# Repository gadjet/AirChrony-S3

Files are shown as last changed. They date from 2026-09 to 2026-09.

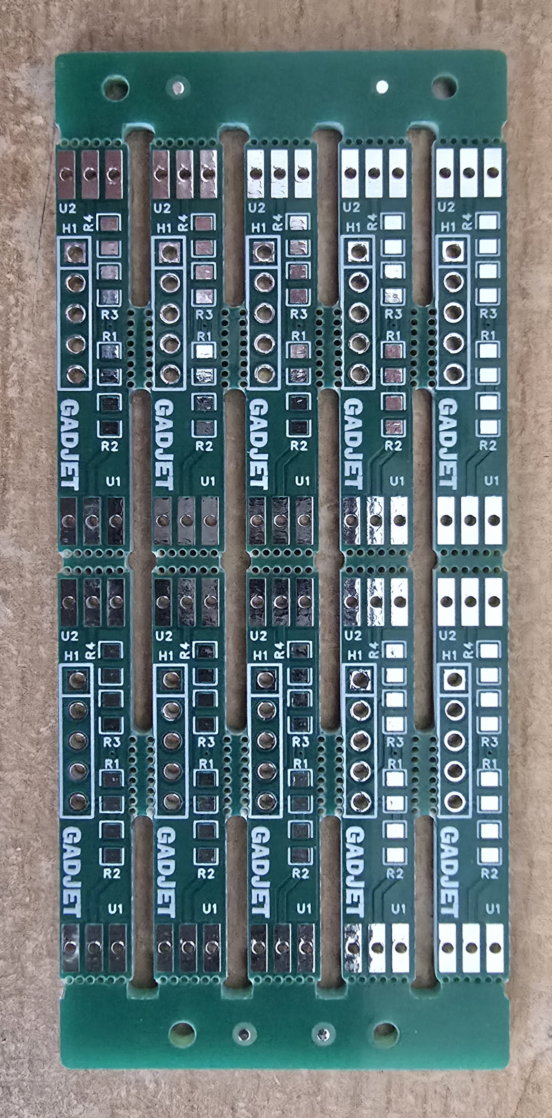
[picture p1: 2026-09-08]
PCB Files/Detector PCB/20260908_100754.jpg

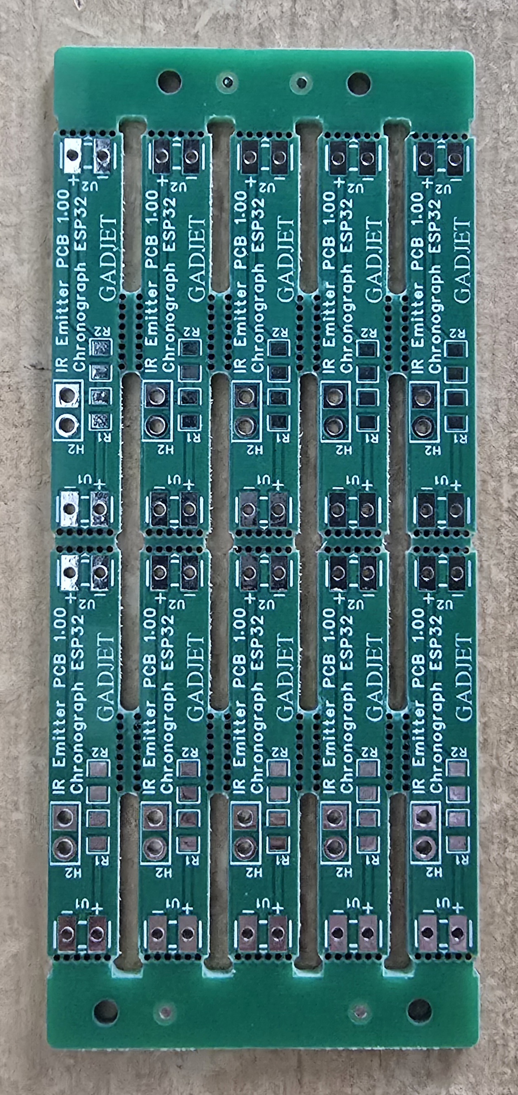
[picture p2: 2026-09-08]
PCB Files/Emitter PCB/20260908_100842.jpg

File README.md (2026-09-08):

# AirChrony-S3
DIY Chronograph revisited

This project is still a work in progress.
It's been about 10 years since my first blog entry on my DIY chronograph using an Ardunino Nano and a Bluetooth transmitter.  This connected to an app on my phone and transmitted the time between trigger 1 and 2, which the app then used, along with the pellet weight, to calculate the speed and power of the rifle/pistol.

I have a few projects under my belt since then and although I enjoy designing the hardware I'm not so good at writing the software needed to operate it.

As many others have done I've started using AI, specifically Google Gemini, to help writing code for, not just the hardware, but also the user interface on the phone/PC.

I realised that I could revisit the DIY Chronograph using an EPS32, my favorite being the Xiao ESP32 - S3 from Seeedstudio.  This runs at 240MHz which is a little faster than the older Arduino Nano and with it also having it's own webserver capability I could include the user interface on the Chronograph itself and just visit the webpage to interact with the device (this can be done on your phone, tablet or laptop).

Hardware
The basics are much the same as the original design with a couple of IR emitters and detectors spaced 50mm apart creating two beams that when broken start and end a timer that measures how long it takes for the pellet to travel 50mm and from that the speed of the pellet can be determined.

Chronograph - Top Down Section View
**General layout
**
Chronograph - Side Section View
General layout Side Sectionpng
 
Chronograph - X-RAY View
X-Ray View

The outer casing is made in two parts that slide over the electronics and tube, they interface using two 2mm dowels and an M3 screw to lock them together.


Currently power is supplied using a USB C lead from a 5V power source but I may add an internal battery later.  Please note: the USB power lead head will need to be narrow enough to fit in the recess which is 11.5mm x 6.5mm.

With the original design this "time" value was transmitted to the phone where the app would calculate the speed/power etc. with the ESP32 solution all the calculations are done on the device and placed on the webpage on the ESP32 server.  To view the User Interface you just connect you device to the WiFi "AirChrony3" then visit "192.168.4.1" with your browser.
User interface
The user interface opens to show the current shot data on the "Live Chrono" tab, there are other tabs including "Pellet profiles" here you can add details of your pellets like brand and size and weight, you can pick from these profiles to calculate the power of the airgun.  There is also a "settings" tab where you can change things like voice announcements, distance between the sensors and other things.

This interface is constantly under revision as I think of new things and you are welcome to use AI to create your own specific user interface.

## Assembled parts






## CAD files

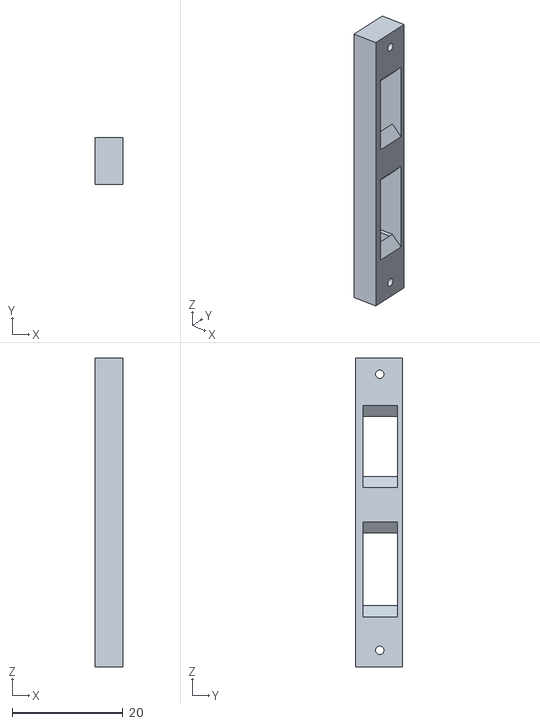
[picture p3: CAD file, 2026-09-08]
3D STL files/Emitter_Detector assembley jig.stl
5.08 x 8.44 x 55.9

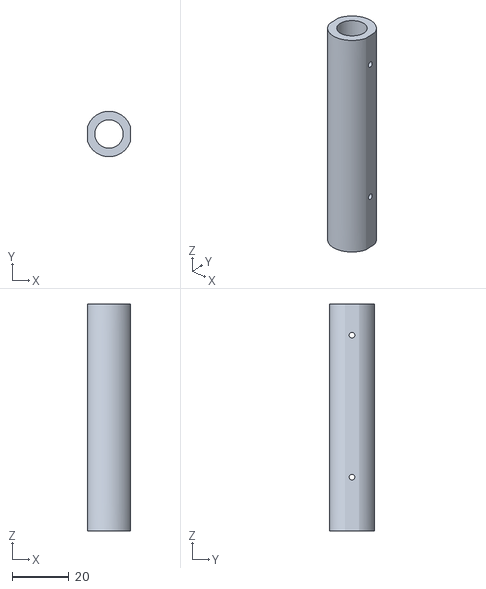
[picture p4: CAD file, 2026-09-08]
3D STL files/Tube.stl
15.3 x 16.0 x 80.0

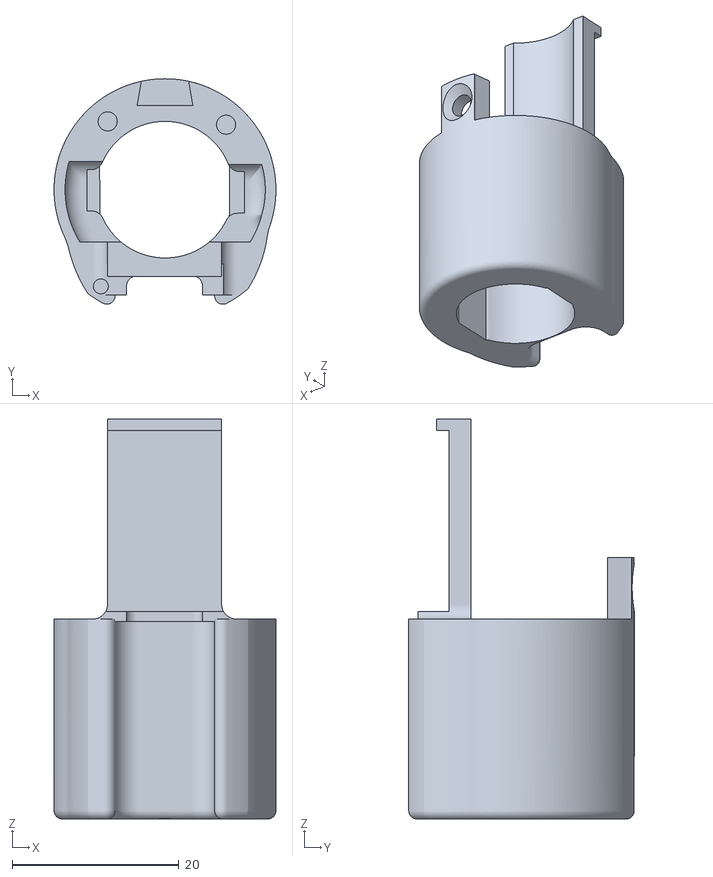
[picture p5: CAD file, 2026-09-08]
3D STL files/Front.stl
26.6 x 27.1 x 48.0

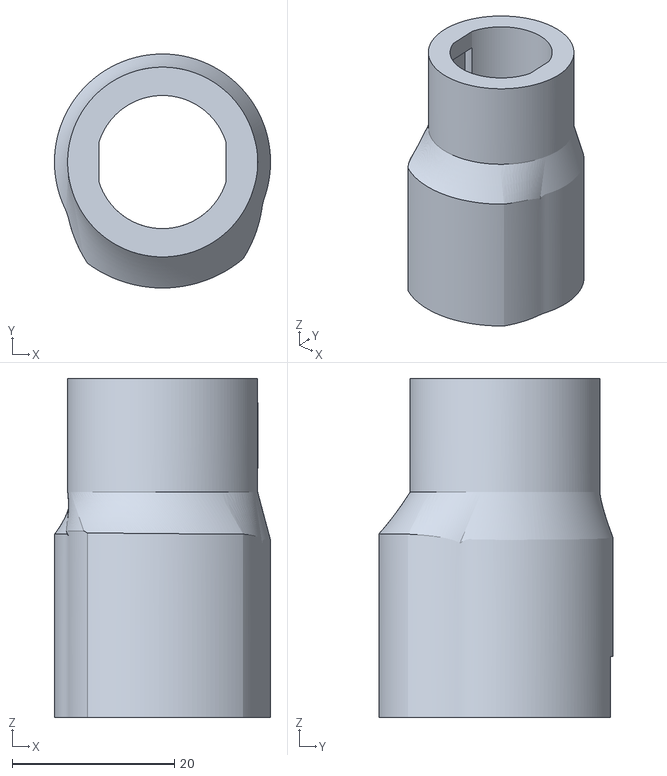
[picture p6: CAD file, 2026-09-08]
3D STL files/Rear.stl
26.6 x 28.8 x 41.8

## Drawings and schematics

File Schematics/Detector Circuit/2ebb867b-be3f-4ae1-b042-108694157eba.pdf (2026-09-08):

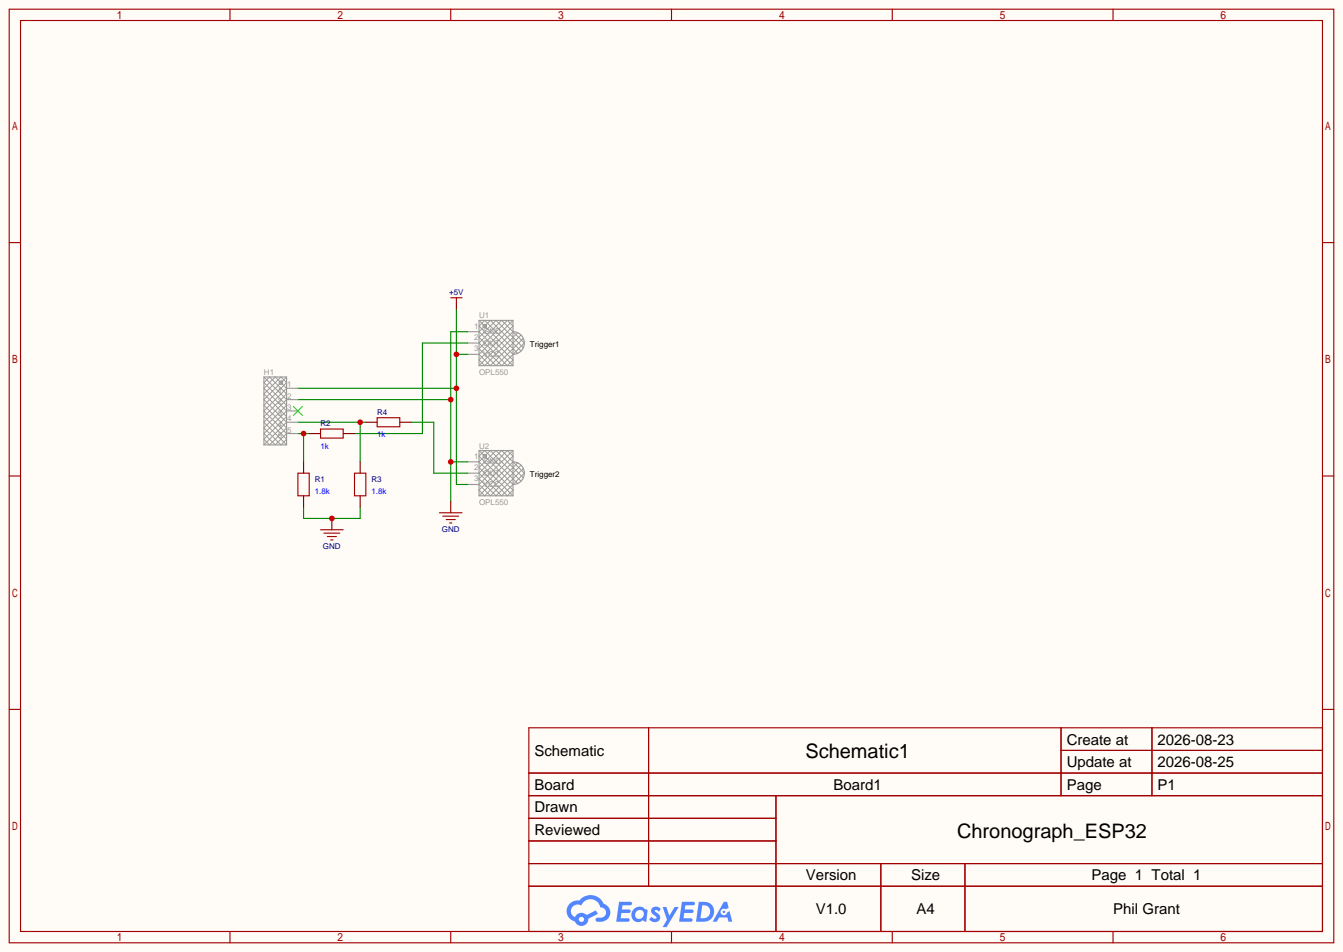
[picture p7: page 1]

Schematic | Schematic1 | Create at | 2026-08-23

Update at | 2026-08-25

Board | Board1 | Page | P1
Drawn | | Chronograph_ESP32
Reviewed

Version | Size | Page 1 Total 1
V1.0 | A4 | Phil Grant

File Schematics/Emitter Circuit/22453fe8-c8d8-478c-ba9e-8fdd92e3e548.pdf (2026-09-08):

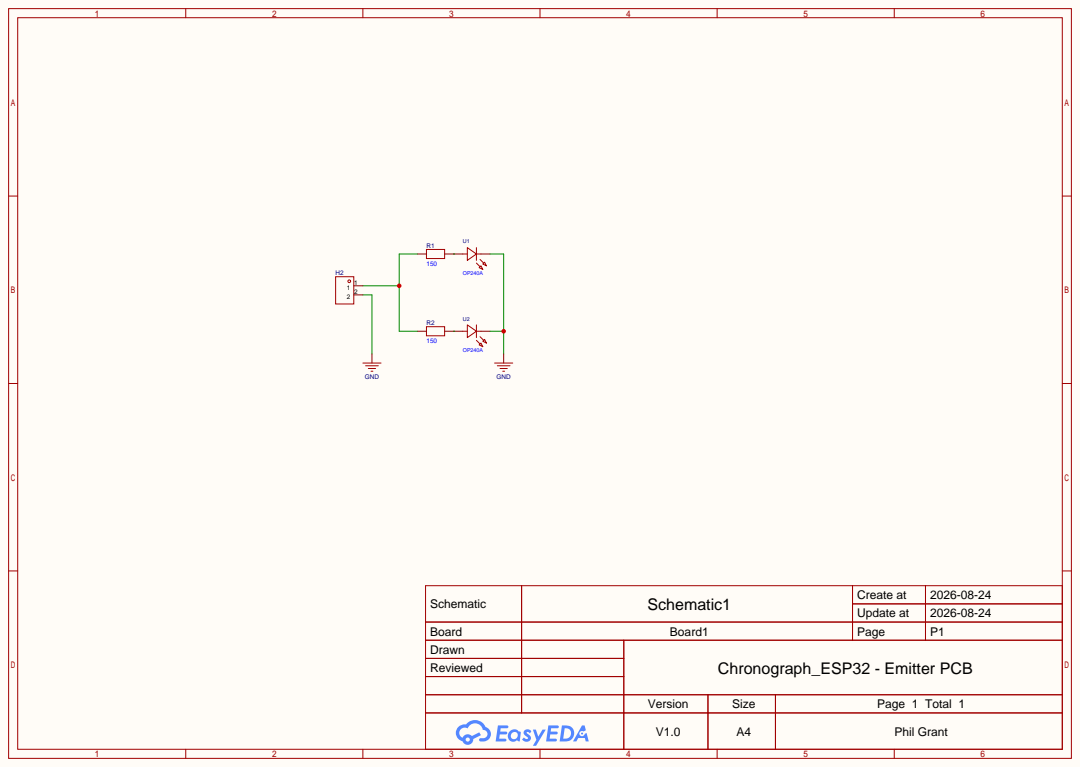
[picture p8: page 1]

Schematic | Schematic1 | Create at | 2026-08-24

Update at | 2026-08-24

Board | Board1 | Page | P1
Drawn | | Chronograph_ESP32 - Emitter PCB
Reviewed

Version | Size | Page 1 Total 1
V1.0 | A4 | Phil Grant

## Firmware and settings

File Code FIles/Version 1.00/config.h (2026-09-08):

#ifndef CONFIG_H
#define CONFIG_H

#include <Arduino.h>

// ==============================================================================
// HARDWARE PIN DEFINITIONS FOR SEED STUDIO XIAO ESP32-S3
// ==============================================================================
// Seeed Studio XIAO ESP32-S3 Pin Mapping:
// D0 -> GPIO 1  (Assigned to: IR Emitters Ground Sink - LOW)
// D1 -> GPIO 2  (Assigned to: IR Emitters Power Control via 2x 150Ω resistors - HIGH)
// D2 -> GPIO 3
// D3 -> GPIO 4
// D4 -> GPIO 5
// D5 -> GPIO 6
// D6 -> GPIO 43 (TX)
// D7 -> GPIO 44 (RX)
// D8 -> GPIO 7  (SCL)
// D9 -> GPIO 8  (Assigned to: Gate 2 Stop Sensor DOUT)
// D10-> GPIO 9  (Assigned to: Gate 1 Start Sensor DOUT)
// Built-in User LED: GPIO 21 (Active LOW on XIAO ESP32-S3)
// ==============================================================================

#if defined(CONFIG_IDF_TARGET_ESP32C3)
  #define PIN_GATE_1          10  // D10 on XIAO C3 (GPIO 10) - First optical IR sensor (Start)
  #define PIN_GATE_2          9   // D9  on XIAO C3 (GPIO 9)  - Second optical IR sensor (Stop)
  #define PIN_IR_EMITTER      3   // D1  on XIAO C3 (GPIO 3)  - Power feed (HIGH) to 2x IR emitter LEDs
  #define PIN_IR_EMITTER_GND  2   // D0  on XIAO C3 (GPIO 2)  - Ground sink (LOW) for 2x IR emitter LEDs
  #define PIN_STATUS_LED      10  // Built-in LED on XIAO C3
#else
  #define PIN_GATE_1          9   // D10 on XIAO S3 (GPIO 9)  - First optical IR sensor (Start)
  #define PIN_GATE_2          8   // D9  on XIAO S3 (GPIO 8)  - Second optical IR sensor (Stop)
  #define PIN_IR_EMITTER      2   // D1  on XIAO S3 (GPIO 2)  - Power feed (HIGH) to 2x IR emitter LEDs via 150Ω
  #define PIN_IR_EMITTER_GND  1   // D0  on XIAO S3 (GPIO 1)  - Ground sink (LOW) for 2x IR emitter LEDs
  #define PIN_STATUS_LED      21  // On-board LED for visual shot / AP indication (Active LOW on XIAO S3)
#endif

// Default trigger interrupt mode:
// Most digital IR receiver boards (phototransistor + LM393 comparator) output LOW
// when the IR beam is interrupted (falling edge) or HIGH (rising edge).
#define DEFAULT_TRIGGER_MODE FALLING 

// ==============================================================================
// DEFAULT MEASUREMENT & POWER SAVING PARAMETERS
// ==============================================================================
#define DEFAULT_GATE_DISTANCE_MM    50.0f    // Distance between Gate 1 and Gate 2 in millimeters
#define MIN_GATE_DISTANCE_MM        10.0f
#define MAX_GATE_DISTANCE_MM        300.0f

#define SHOT_TIMEOUT_MICROS         500000UL // 500ms timeout (allows slow gravity drop testing and low velocity projectiles)
#define MIN_SHOT_INTERVAL_MICROS    50000UL  // 50ms dead-time after a shot before arming next

#define DEFAULT_EMITTER_TIMEOUT_MIN 10       // Emitter power-saving sleep timeout in minutes (0 = always on)

// ==============================================================================
// DEFAULT PELLET SETTINGS
// ==============================================================================
#define DEFAULT_PELLET_BRAND        "JSB"
#define DEFAULT_PELLET_MODEL        "Exact Diabolo"
#define DEFAULT_PELLET_GRAINS       8.44f
#define DEFAULT_CALIBER             ".177 (4.5mm)"
#define DEFAULT_AVG_WINDOW          10       // Default rolling average shot window

// Unit Conversion Constants
#define GRAINS_TO_GRAMS             0.06479891f
#define GRAMS_TO_GRAINS             15.4323584f
#define MPS_TO_FPS                  3.280839895f
#define FPS_TO_MPS                  0.3048f
#define JOULES_TO_FTLBS             0.737562149f
#define FTLBS_TO_JOULES             1.355817948f

// ==============================================================================
// WIFI & ACCESS POINT CONFIGURATION
// ==============================================================================
#define AP_SSID                     "AirChrony-S3"
#define AP_PASSWORD                 ""          // Open network by default for convenience
#define AP_CHANNEL                  1
#define AP_MAX_CONN                 4

#define MDNS_HOSTNAME               "chronograph" // Accessible at http://chronograph.local

#define MAX_SHOTS_PER_STRING        250         // Memory safety buffer for single string
#define MAX_SAVED_STRINGS           50          // Max string files stored in LittleFS

#endif // CONFIG_H

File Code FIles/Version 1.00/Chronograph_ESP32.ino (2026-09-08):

#include <Arduino.h>
#include <WiFi.h>
#include <WebServer.h>
#include <DNSServer.h>
#include <ESPmDNS.h>
#include "config.h"
#include "ChronoEngine.h"
#include "StorageManager.h"
#include "WebPages.h"

// Core Engines
ChronoEngine engine;
StorageManager storage;

// Networking
WebServer server(80);
DNSServer dnsServer;
const byte DNS_PORT = 53;

// Helper to extract JSON parameter from body
String getJsonField(const String& body, const String& field) {
    int idx = body.indexOf("\"" + field + "\"");
    if (idx == -1) return "";
    int colon = body.indexOf(':', idx);
    if (colon == -1) return "";
    int start = colon + 1;
    while (start < (int)body.length() && (body[start] == ' ' || body[start] == '\t' || body[start] == '\n' || body[start] == '\r')) start++;
    if (start >= (int)body.length()) return "";

    if (body[start] == '\"') {
        int end = body.indexOf('\"', start + 1);
        if (end == -1) return "";
        return body.substring(start + 1, end);
    } else {
        int end = start;
        while (end < (int)body.length() && body[end] != ',' && body[end] != '}' && body[end] != ' ' && body[end] != '\n' && body[end] != '\r') end++;
        return body.substring(start, end);
    }
}

// HTTP Route Handlers
void handleRoot() {
    engine.refreshActivity();
    server.send_P(200, "text/html", PAGE_INDEX);
}

void handleGetState() {
    String json = storage.stringToJson(engine);
    server.send(200, "application/json", json);
}

void handleGetLive() {
    String json = "{";
    json += "\"totalShots\":" + String(engine.shots.size()) + ",";
    json += "\"state\":" + String((int)engine.getState()) + ",";
    json += "\"emittersPowered\":" + String(engine.emittersPowered ? "true" : "false");
    json += "}";
    server.send(200, "application/json", json);
}

void handlePostPellet() {
    engine.refreshActivity();
    if (server.hasArg("plain")) {
        String body = server.arg("plain");
        
        String brand = getJsonField(body, "brand");
        if (brand.length() > 0) engine.pellet.brand = brand;

        String model = getJsonField(body, "model");
        if (model.length() > 0) engine.pellet.model = model;

        String cal = getJsonField(body, "caliber");
        if (cal.length() > 0) engine.pellet.caliber = cal;

        String gr = getJsonField(body, "weightGrains");
        if (gr.length() > 0) engine.pellet.setWeightGrains(gr.toFloat());

        String win = getJsonField(body, "avgWindowSize");
        if (win.length() > 0) engine.avgWindowSize = win.toInt();

        engine.recalculateStatistics();
        storage.saveSettings(engine);

        server.send(200, "application/json", "{\"status\":\"ok\"}");
        return;
    }
    server.send(400, "application/json", "{\"error\":\"Missing body\"}");
}

void handlePostHardware() {
    engine.refreshActivity();
    if (server.hasArg("plain")) {
        String body = server.arg("plain");
        
        String dist = getJsonField(body, "gateDistanceMm");
        if (dist.length() > 0) engine.gateDistanceMm = dist.toFloat();

        String trig = getJsonField(body, "triggerMode");
        if (trig.length() > 0) {
            engine.triggerMode = trig.toInt();
            engine.attachGateInterrupts();
        }

        String emitTimeout = getJsonField(body, "emitterTimeoutMin");
        if (emitTimeout.length() > 0) {
            engine.emitterTimeoutMin = emitTimeout.toInt();
        }

        storage.saveSettings(engine);
        server.send(200, "application/json", "{\"status\":\"ok\"}");
        return;
    }
    server.send(400, "application/json", "{\"error\":\"Missing body\"}");
}

void handlePostEmitters() {
    engine.refreshActivity();
    if (server.hasArg("plain")) {
        String body = server.arg("plain");
        String en = getJsonField(body, "enabled");
        if (en == "true") {
            engine.setEmitters(true);
        } else if (en == "false") {
            engine.setEmitters(false);
        } else {
            // Toggle
            engine.setEmitters(!engine.emittersPowered);
        }
    } else {
        engine.setEmitters(!engine.emittersPowered);
    }
    String json = "{\"status\":\"ok\",\"emittersPowered\":" + String(engine.emittersPowered ? "true" : "false") + "}";
    server.send(200, "application/json", json);
}

void handleGetSensors() {
    engine.refreshActivity();
    // Read direct digital pin states for sensor alignment test
    bool g1 = (digitalRead(PIN_GATE_1) == (engine.triggerMode == FALLING ? LOW : HIGH));
    bool g2 = (digitalRead(PIN_GATE_2) == (engine.triggerMode == FALLING ? LOW : HIGH));

    String json = "{";
    json += "\"gate1\":" + String(g1 ? "true" : "false") + ",";
    json += "\"gate2\":" + String(g2 ? "true" : "false") + ",";
    json += "\"emittersPowered\":" + String(engine.emittersPowered ? "true" : "false");
    json += "}";
    server.send(200, "application/json", json);
}

void handleSimulateShot() {
    engine.simulateShot(785.0f, 6.0f);
    server.send(200, "application/json", "{\"status\":\"simulated\"}");
}

void handleDeleteShot() {
    engine.refreshActivity();
    if (server.hasArg("index")) {
        int idx = server.arg("index").toInt();
        engine.deleteShot(idx);
        server.send(200, "application/json", "{\"status\":\"deleted\"}");
        return;
    }
    server.send(400, "application/json", "{\"error\":\"Missing index\"}");
}

void handleResetSession() {
    engine.resetSession();
    server.send(200, "application/json", "{\"status\":\"reset\"}");
}

void handleSaveString() {
    engine.refreshActivity();
    String name = "";
    if (server.hasArg("plain")) {
        name = getJsonField(server.arg("plain"), "name");
    }
    String id = storage.saveShotString(engine, name);
    if (id.length() > 0) {
        server.send(200, "application/json", "{\"status\":\"saved\",\"id\":\"" + id + "\"}");
    } else {
        server.send(500, "application/json", "{\"error\":\"Save failed\"}");
    }
}

void handleListStrings() {
    engine.refreshActivity();
    String listJson = storage.listSavedStrings();
    server.send(200, "application/json", listJson);
}

void handleLoadString() {
    engine.refreshActivity();
    if (server.hasArg("id")) {
        String id = server.arg("id");
        String json = storage.getShotStringJson(id);
        if (json.length() > 2) {
            server.send(200, "application/json", json);
            return;
        }
    }
    server.send(404, "application/json", "{\"error\":\"Not found\"}");
}

void handleDeleteSavedString() {
    engine.refreshActivity();
    if (server.hasArg("id")) {
        String id = server.arg("id");
        storage.deleteShotString(id);
        server.send(200, "application/json", "{\"status\":\"deleted\"}");
        return;
    }
    server.send(400, "application/json", "{\"error\":\"Missing id\"}");
}

void handleExportActiveCSV() {
    engine.refreshActivity();
    String csv = storage.generateCSV(engine);
    server.sendHeader("Content-Disposition", "attachment; filename=\"active_shot_string.csv\"");
    server.send(200, "text/csv", csv);
}

void handleExportSavedCSV() {
    engine.refreshActivity();
    if (server.hasArg("id")) {
        String id = server.arg("id");
        String json = storage.getShotStringJson(id);
        server.sendHeader("Content-Disposition", "attachment; filename=\"string_" + id + ".json\"");
        server.send(200, "application/json", json);
        return;
    }
    server.send(400, "text/plain", "Missing string id");
}

void handleNotFound() {
    String host = server.hostHeader();
    if (host != "192.168.4.1" && host != "chronograph.local") {
        server.sendHeader("Location", "http://192.168.4.1/", true);
        server.send(302, "text/plain", "");
        return;
    }
    server.send(404, "text/plain", "Not Found");
}

void setup() {
    Serial.begin(115200);
    delay(500);
    Serial.println();
    Serial.println(F("========================================"));
    Serial.println(F("  AirChrony S3 Precision Chronograph    "));
    Serial.println(F("  Gate 1: D10 (GPIO9) | Gate 2: D9 (GPIO8) "));
    Serial.println(F("  IR Emitters: D1 (GPIO2) via 2x 150R   "));
    Serial.println(F("========================================"));

    // Initialize Storage
    storage.begin();

    // Initialize Chronograph Engine & Sensors
    engine.begin();
    storage.loadSettings(engine);

    // Initialize WiFi in Access Point mode
    WiFi.mode(WIFI_AP);
    IPAddress local_ip(192, 168, 4, 1);
    IPAddress gateway(192, 168, 4, 1);
    IPAddress subnet(255, 255, 255, 0);
    WiFi.softAPConfig(local_ip, gateway, subnet);
    WiFi.softAP(AP_SSID, AP_PASSWORD, AP_CHANNEL, 0, AP_MAX_CONN);

    Serial.print(F("[WiFi] Access Point Created: "));
    Serial.println(AP_SSID);
    Serial.print(F("[WiFi] Connect to: http://"));
    Serial.println(WiFi.softAPIP());

    // Start DNS Captive Portal
    dnsServer.setErrorReplyCode(DNSReplyCode::NoError);
    dnsServer.start(DNS_PORT, "*", local_ip);

    // Start mDNS Responder
    if (MDNS.begin(MDNS_HOSTNAME)) {
        Serial.println(F("[mDNS] Responding at http://chronograph.local"));
        MDNS.addService("http", "tcp", 80);
    }

    // Configure WebServer Routes
    server.on("/", HTTP_GET, handleRoot);
    server.on("/api/state", HTTP_GET, handleGetState);
    server.on("/api/live", HTTP_GET, handleGetLive);
    server.on("/api/pellet", HTTP_POST, handlePostPellet);
    server.on("/api/hardware", HTTP_POST, handlePostHardware);
    server.on("/api/emitters", HTTP_POST, handlePostEmitters);
    server.on("/api/sensors", HTTP_GET, handleGetSensors);
    server.on("/api/simulate", HTTP_POST, handleSimulateShot);
    server.on("/api/shot/delete", HTTP_POST, handleDeleteShot);
    server.on("/api/reset", HTTP_POST, handleResetSession);
    server.on("/api/string/save", HTTP_POST, handleSaveString);
    server.on("/api/string/list", HTTP_GET, handleListStrings);
    server.on("/api/string/load", HTTP_GET, handleLoadString);
    server.on("/api/string/delete", HTTP_POST, handleDeleteSavedString);
    server.on("/api/export/csv", HTTP_GET, handleExportActiveCSV);
    server.on("/api/string/csv", HTTP_GET, handleExportSavedCSV);

    // Captive Portal probe endpoints (iOS, Android, Windows)
    server.on("/hotspot-detect.html", HTTP_GET, handleRoot);
    server.on("/generate_204", HTTP_GET, handleRoot);
    server.on("/canonical.html", HTTP_GET, handleRoot);
    server.on("/ncsi.txt", HTTP_GET, handleRoot);

    server.onNotFound(handleNotFound);
    server.begin();
    Serial.println(F("[WebServer] Chronograph Web Server is live!"));
}

void loop() {
    // Real-time chronograph interrupt state machine & sleep management
    engine.update();

    // DNS captive portal handling
    dnsServer.processNextRequest();

    // Handle incoming web client requests
    server.handleClient();
}
